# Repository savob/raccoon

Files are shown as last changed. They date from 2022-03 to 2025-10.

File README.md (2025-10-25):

# Raccoon

A little raccoon trinket based on an ATtiny and capacitive sensing. The premise is simple, a small circuitboard decorated to be a raccoon on one side has circuitry mounted on the back to illuminate the LED eyes when a touch is detected on the raccoon. Designed to maximize battery life and run of standard coin cells.

My first foray into making PCB art hardwarewise, and both capacitive sensing and really trying to supress power draw with coding.

_All this artwork was drawn by my lovely sister, Dorotea Bajic. Check out their website [dorotea.ca](https://dorotea.ca/), it's far nicer looking than my own._

# Code

The code is pretty simple for the first two revisions given the scope of the projects, and a minor hack was used to get revision 1.0 working. I used the Arduino framework for the first revision but have since moved to using Microchip's own MPLAB to make full use of the chips.

# Hardware

The electrical design of the system is simple, a microcontroller powered directly from a coin cell battery that is connected to a couple LEDs, a capacitance detection pad, and a select few passive components. The challenge with the board for this was the artwork and making it look nice.

Initially an ATtiny85 was selected but later I switched to the tinyAVR 1-series due to dedicated capacitive sensing hardware and reduced power consumption.

# Software Used

KiCad is used to design the hardware, version 9 as of writing.

Arduino IDE 1.8.13 was used to program revision 1.0. MPLAB for revisions 2.0 onwards.

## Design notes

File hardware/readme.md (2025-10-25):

# Raccoon Hardware Files

The folders `raccoon_revX` are the actual KiCad projects, `raccoon-art` is the collection of footprints for the artwork derived from the images in the [media](../media/) folder.

# Revision 1.0

These design files are the lightly adjusted version of the original raccoon hardware, to address the hardware bugs related to the programming interface.

# Revision 2.0

A continuation of the work done for the files shared as "Revision 1". Changes from the previous revision:

- Complete removal of the ATtiny85 in favour of the ATtiny1617 _which is definitely overkill for this task but what I had on hand._
- Moved to using a TagConnect programming header to simplify programming. _This does slightly affect the art on the front._
- Added a jumper to cut for current measurement

# Revision 3.0

Tweaking the design of revision 2.0. Changes from the previous revision:

- Changed the main microcontroller to a 1616 since we don't need many GPIO, but I want flash space to try different eye effects, maybe even changing with each touch
- Removed unnecessary passives; the sense resistor, VREF capacitor, secondary decoupling capacitor (100n)
- Split the LED lines for individual eye control, via PWM
- Moved the programming pads to be closer to the edge so some alignment pins align to the PCB outline instead of needing holes in the PCB
- Moved the LED current limiting resistors to be closer to the microcontroller and out of the path of the coin cell
- Added a keepout zone for pour near the current measurement jumper to avoid cutting and then shorting VCC to GND

# Software Used

KiCad version 9 was used for all project files.

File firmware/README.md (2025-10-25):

# Firmware

With each change of hardware, the firmware needed to change too. This contains the firmware for all revisions.

## Software Used

Arduino IDE 1.8.13 was used to program the microcontroller for the first deign, but in later revisions I moved to MPLAB to try it out and was pleased with the results.

# Revision 1.0 - `sleepingCapSense`

I used the [TinyTouchLib](https://github.com/cpldcpu/TinyTouchLib) library made by [cpldcpu](https://github.com/cpldcpu). I had some issues using it as a conventional library in Arduino, so I opted to simply copy the files I needed directly into the sketch folder and modified them slightly to work. Other than the file modifications required to get it to compile, I only changed the the sensitivities to suit the final circuit board and pad. Otherwise the code I use related to capacitive sensing in my sketch is taken directly from the library's example.

The code simply checks for if there is a press event and then flashes the eyes.

## Power Reduction

This relies heavily on the `avr/power` library, and some of my own register manipulations to disable features and put the microcontroller into sleep for the majority of the timer. The watchdog timer (WDT) is used to awake the system periodically to perform the sensing routine. 

## ATtiny85 Support

Support for this microcontroller in the Arduino IDE is provided by the [ATTinyCore](https://github.com/SpenceKonde/ATTinyCore) project hosted by [Spence Konde](https://github.com/SpenceKonde).

# Revision 2.0 - `raccoon_rev_2_0.X`

I didn't intend to change the behaviour of the system, I just wanted to port what working in Rev. 1.0 to the ATtiny1617 from the ATtiny85.

Since I was moving to the to the tinyAVR 1-series of chips with the ATtiny1617, I would need to rewrite the entire firmware for the new hardware, especially to make use of the 1617's built in Peripheral Touch Controller (PTC) peripheral for capacitive sensing rather than the ADC trickery used in revision 1.0. 

Since I was basically starting from scratch, I took the opprotunity to try out Microchip's own toolchain and pivoted to using MPLAB. Once I learned my way though their project configuration system **I had the firmware complete in a single evening!**

## Power Reduction

Using the generated project files from MPLAB and following their example after specifying "low-power" for my capacitive sensing pad the performance was what I hoped for! I measured an average current draw of 15&nbsp;uA when sensing which was better than revision 1.0, and it was also more responsive! Kudos to their team! 

# Revision 3.0 - `raccoon_rev_3_0.X`

I've prepared the core of the project in MPLAB, but I haven't actually written code yet to drive the LEDs with PWM (I previously just used conventional digital outputs).

With revision 3.0 I would like to take the time to try out more effects to make it seem a bit more lifelike and amusing to interact with compared to earlier revisions. Some ideas:

- Diming them instead of hard on/offs
- Having the LED brightness not be synchronized between eyes, as though its "eye"s are opening cartoonishly out of slumber
- Using an intermediate level of brightness and then repeated touches make it go full power

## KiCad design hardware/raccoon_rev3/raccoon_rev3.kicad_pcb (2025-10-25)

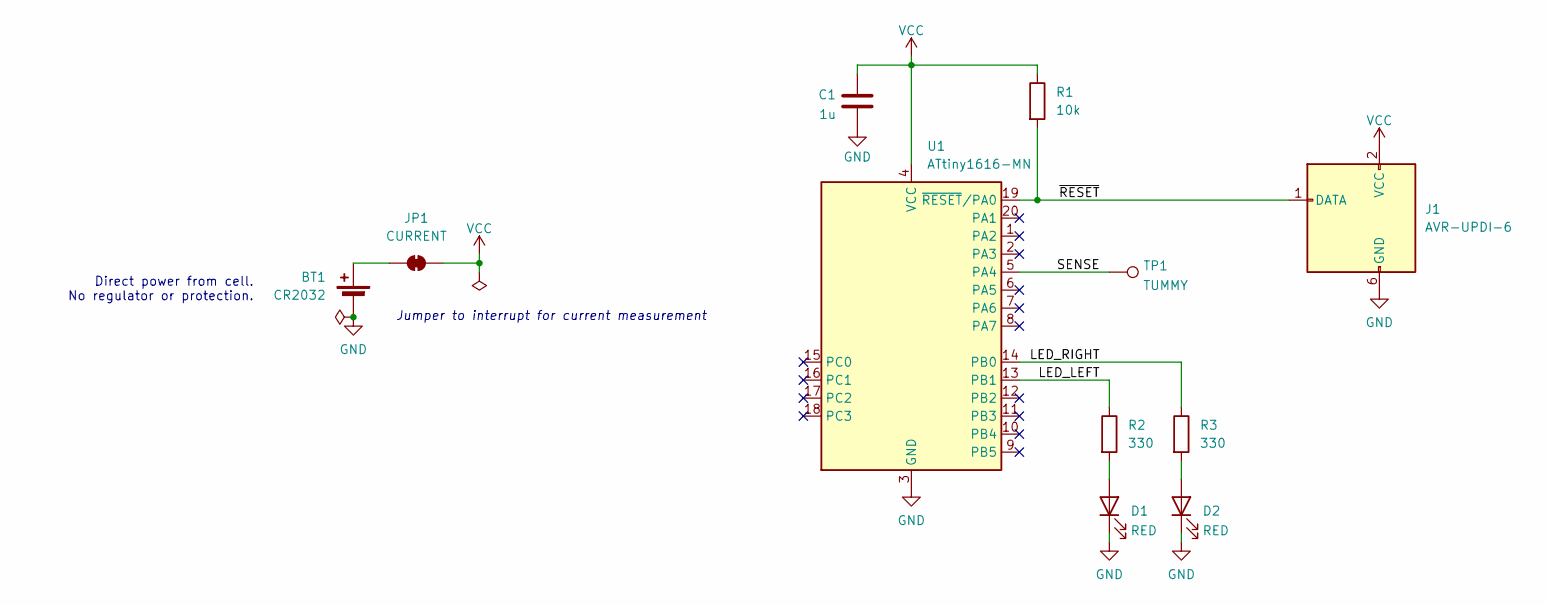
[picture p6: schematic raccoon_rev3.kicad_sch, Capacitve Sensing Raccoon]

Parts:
BT1: CR2032; BatteryHolder_Multicomp_BC-2001_1x2032; Manufacturer PN MY-2032-05; LCSC C964830
C1: 1u; C_0603_1608Metric; Manufacturer PN CL10A105KB8NNNC; LCSC C15849
D1, D2: RED; D_0805_2012Metric; Manufacturer PN LTST-C170KRKT; LCSC C94868
J1: AVR-UPDI-6; Tag-Connect_TC2030-IDC-NL_2x03_P1.27mm_Vertical
JP1: CURRENT; SolderJumper-2_P1.3mm_Bridged2Bar_Pad1.0x1.5mm
R1: 10k; R_0603_1608Metric; Manufacturer PN 0603WAF1002T5E; LCSC C25804
R2, R3: 330; R_0603_1608Metric; Manufacturer PN 0603WAF3300T5E; LCSC C23138
TP1: TUMMY; tummy
U1: ATtiny1616-MN; VQFN-20-1EP_3x3mm_P0.4mm_EP1.7x1.7mm; Manufacturer PN ATTINY1616-MNR; LCSC C507118

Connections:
/LED_LEFT: R2.1, U1.13 (PB1)
/LED_RIGHT: R3.1, U1.14 (PB0)
/SENSE: TP1.1, U1.5 (PA4)
/~RESET: J1.1 (DATA), R1.2, U1.19 (~RESET/PA0)
GND: BT1.2 (-), C1.2, D1.1 (K), D2.1 (K), J1.6 (GND), U1.3 (GND), U1.21 (GND)
unnamed: BT1.1 (+), JP1.1 (A)
unnamed: D1.2 (A), R2.2
unnamed: D2.2 (A), R3.2
VCC: C1.1, J1.2 (VCC), JP1.2 (B), R1.1, U1.4 (VCC)

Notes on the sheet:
Jumper to interrupt for current measurement
Direct power from cell. No regulator or protection.

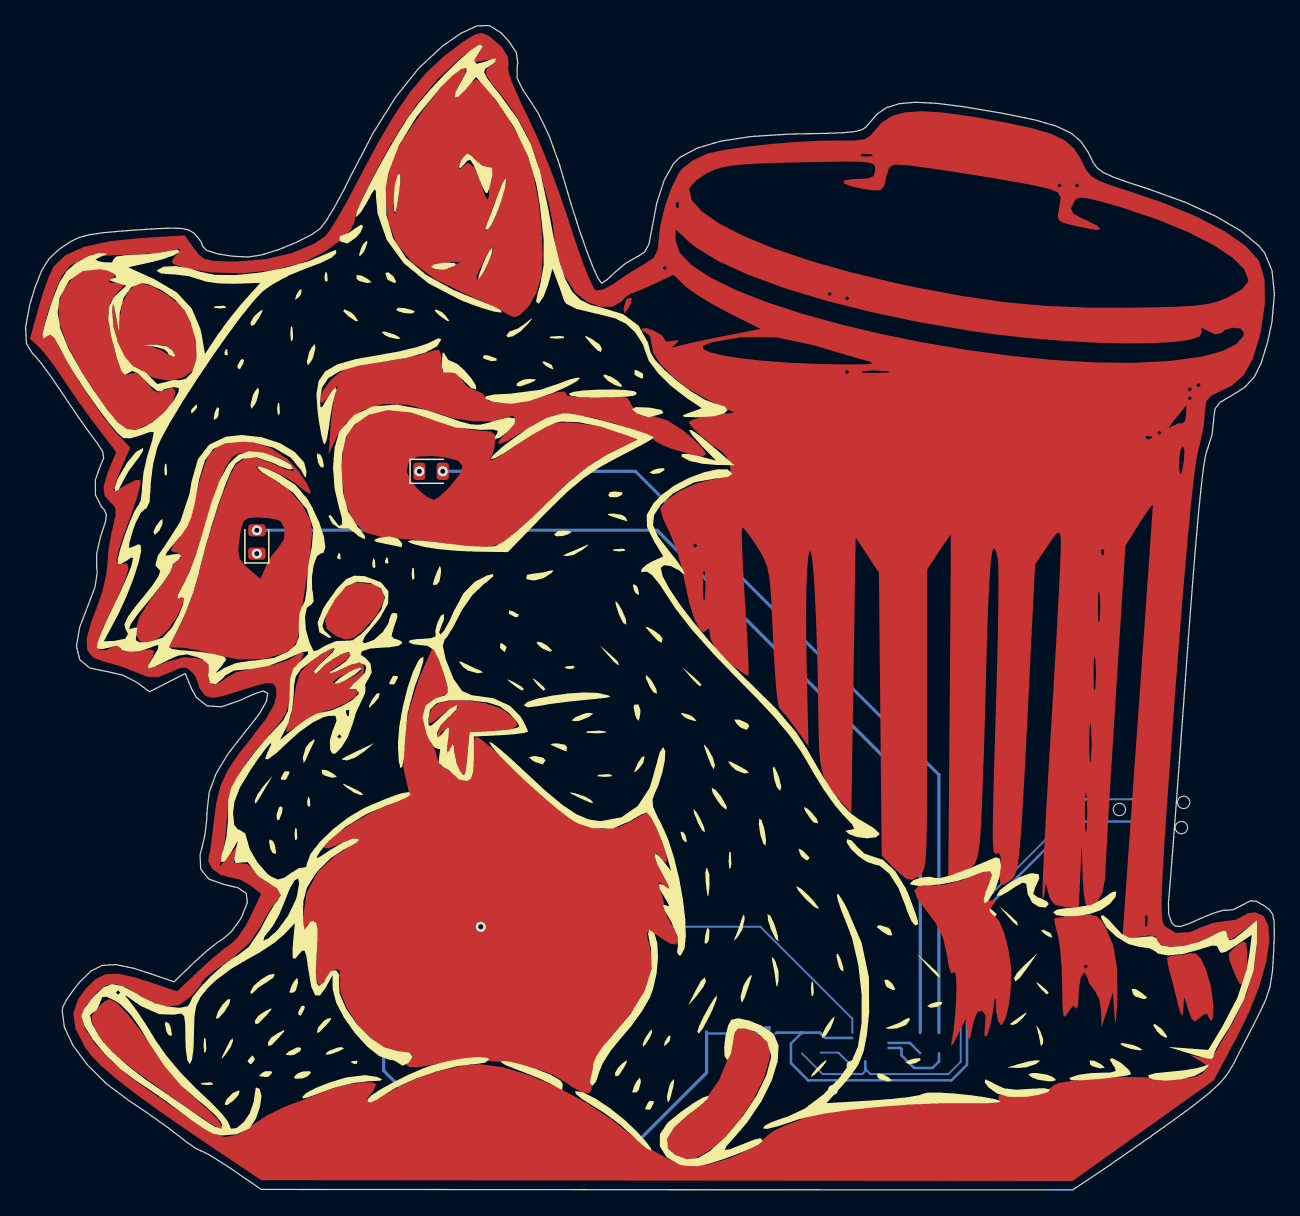
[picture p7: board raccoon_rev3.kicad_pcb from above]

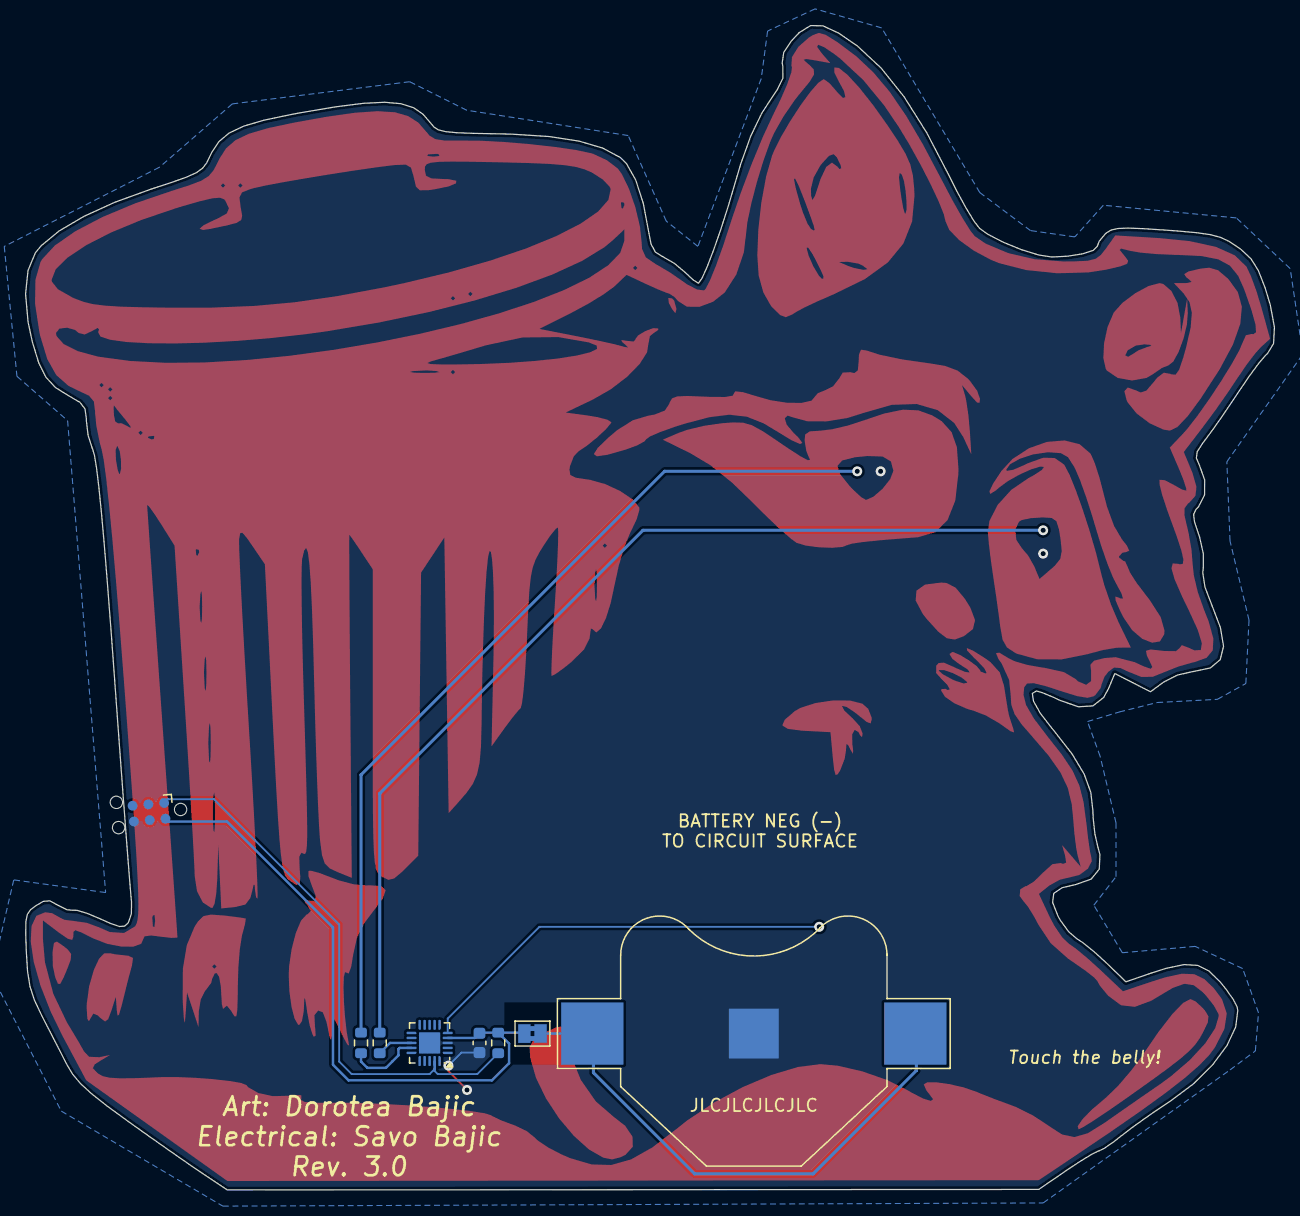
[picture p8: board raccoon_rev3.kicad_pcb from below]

Board: 2 copper layers, 100.2 x 93.4 mm, 11 parts (8 on the bottom side), 9 nets.

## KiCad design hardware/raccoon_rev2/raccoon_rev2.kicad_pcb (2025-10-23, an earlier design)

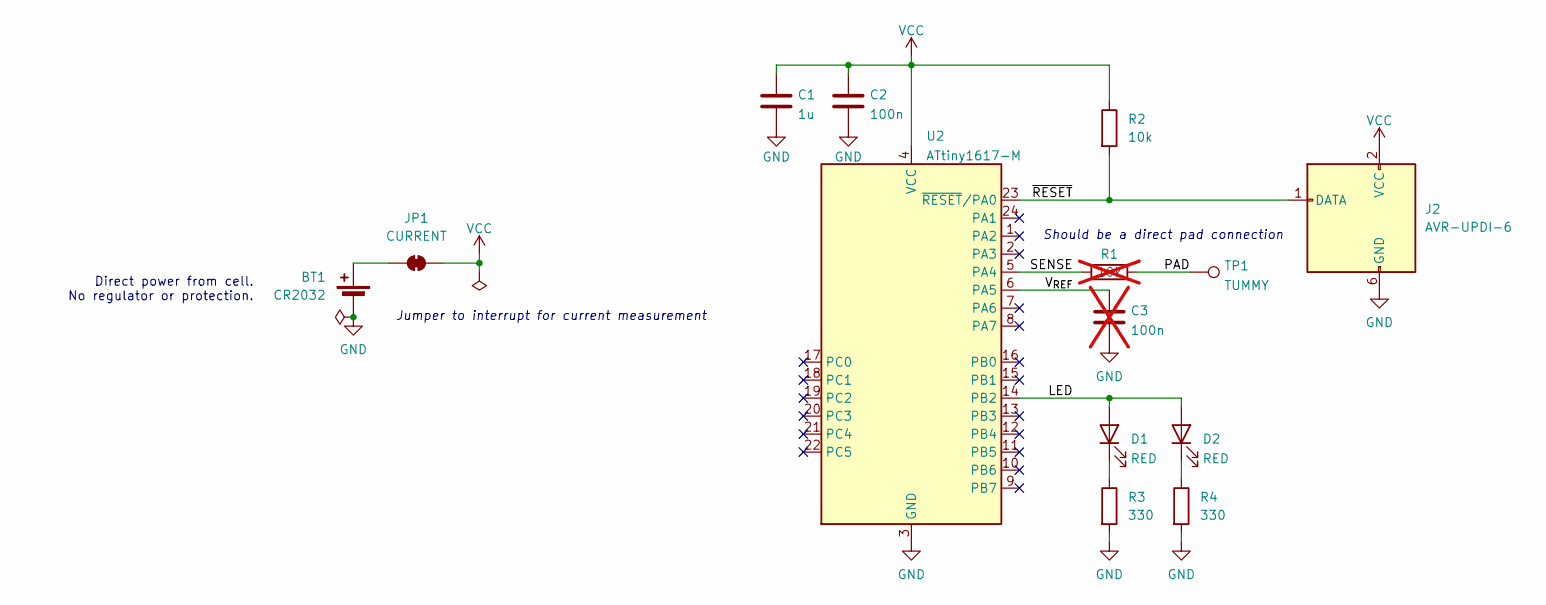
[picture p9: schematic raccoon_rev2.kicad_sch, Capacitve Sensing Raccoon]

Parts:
BT1: CR2032; BatteryHolder_Multicomp_BC-2001_1x2032; Manufacturer PN MY-2032-05; LCSC C964830
C1: 1u; C_0603_1608Metric; Manufacturer PN CL10A105KB8NNNC; LCSC C15849
C2: 100n; C_0603_1608Metric; Manufacturer PN CC0603KRX7R9BB104; LCSC C14663
C3: 100n; C_0603_1608Metric; Manufacturer PN CC0603KRX7R9BB104; LCSC C14663; not fitted
D1, D2: RED; D_0805_2012Metric; Manufacturer PN LTST-C170KRKT; LCSC C94868
J2: AVR-UPDI-6; Tag-Connect_TC2030-IDC-NL_2x03_P1.27mm_Vertical
JP1: CURRENT; SolderJumper-2_P1.3mm_Bridged2Bar_Pad1.0x1.5mm
R1: 10k; R_0603_1608Metric; Manufacturer PN 0603WAF1002T5E; LCSC C25804; not fitted
R2: 10k; R_0603_1608Metric; Manufacturer PN 0603WAF1002T5E; LCSC C25804
R3, R4: 330; R_0603_1608Metric; Manufacturer PN 0603WAF3300T5E; LCSC C23138
TP1: TUMMY; tummy
U2: ATtiny1617-M; QFN-24-1EP_4x4mm_P0.5mm_EP2.6x2.6mm; Manufacturer PN ATTINY1617-MNR; LCSC C614176

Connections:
/LED: D1.2 (A), D2.2 (A), U2.14 (PB2)
/PAD: R1.2, TP1.1
/SENSE: R1.1, U2.5 (PA4)
/V_{REF}: C3.1, U2.6 (PA5)
/~RESET: J2.1 (DATA), R2.2, U2.23 (~RESET/PA0)
GND: BT1.2 (-), C1.2, C2.2, C3.2, J2.6 (GND), R3.2, R4.2, U2.3 (GND), U2.25 (GND)
unnamed: BT1.1 (+), JP1.1 (A)
unnamed: D1.1 (K), R3.1
unnamed: D2.1 (K), R4.1
VCC: C1.1, C2.1, J2.2 (VCC), JP1.2 (B), R2.1, U2.4 (VCC)

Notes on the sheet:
Should be a direct pad connection
Jumper to interrupt for current measurement
Direct power from cell. No regulator or protection.

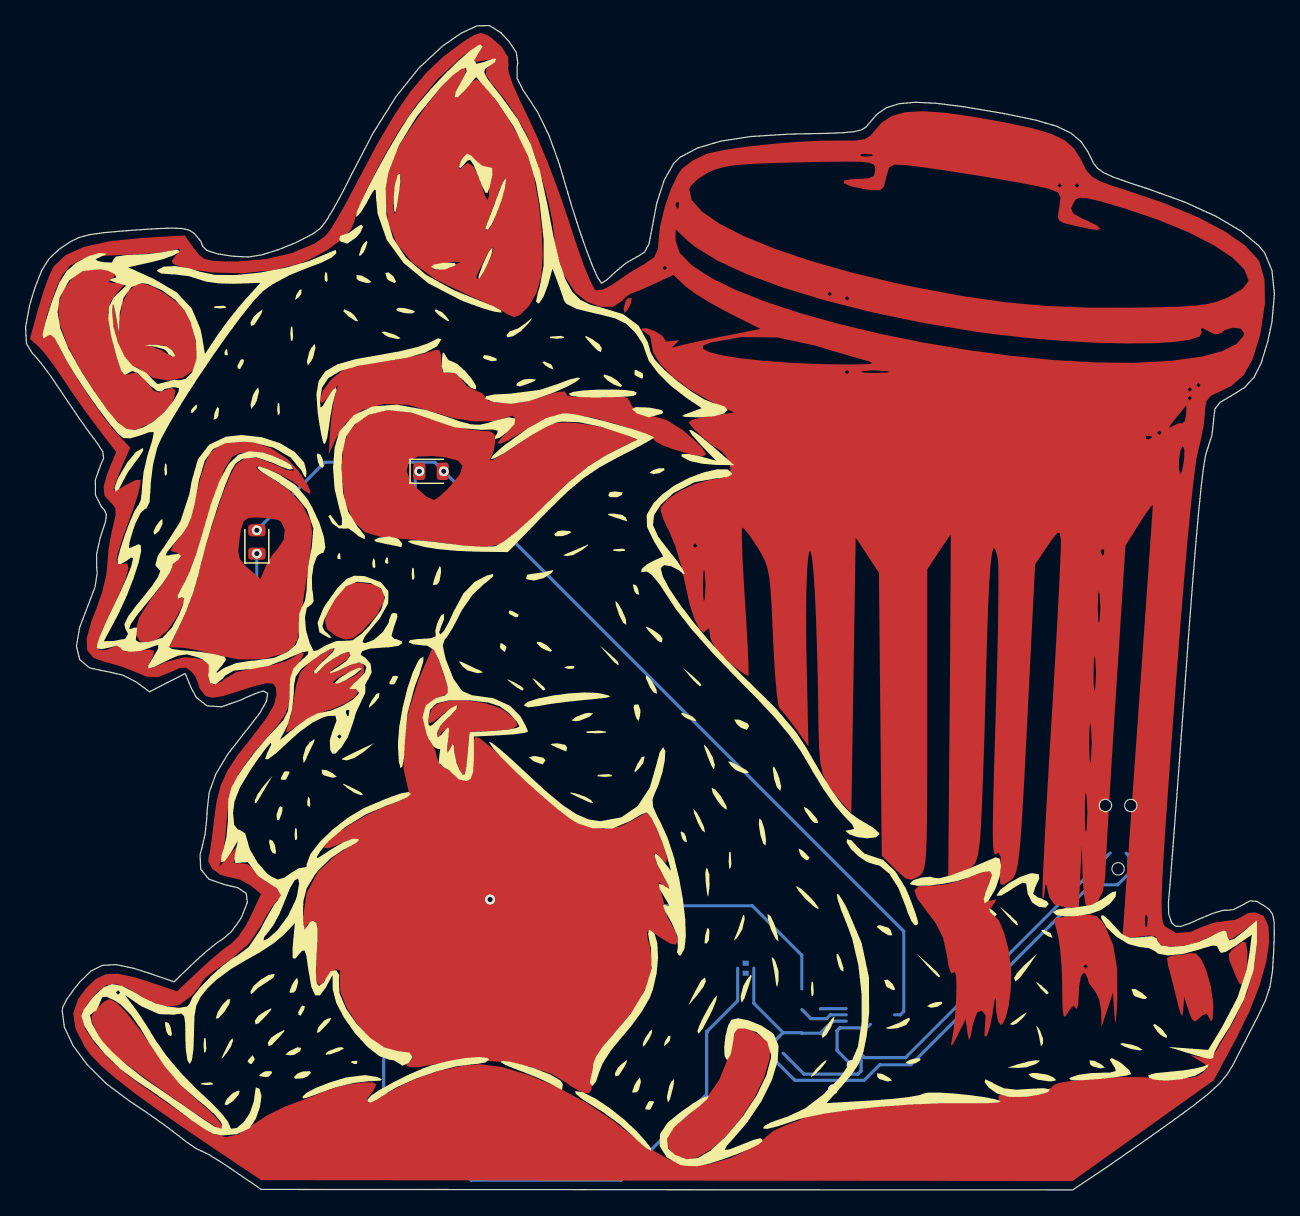
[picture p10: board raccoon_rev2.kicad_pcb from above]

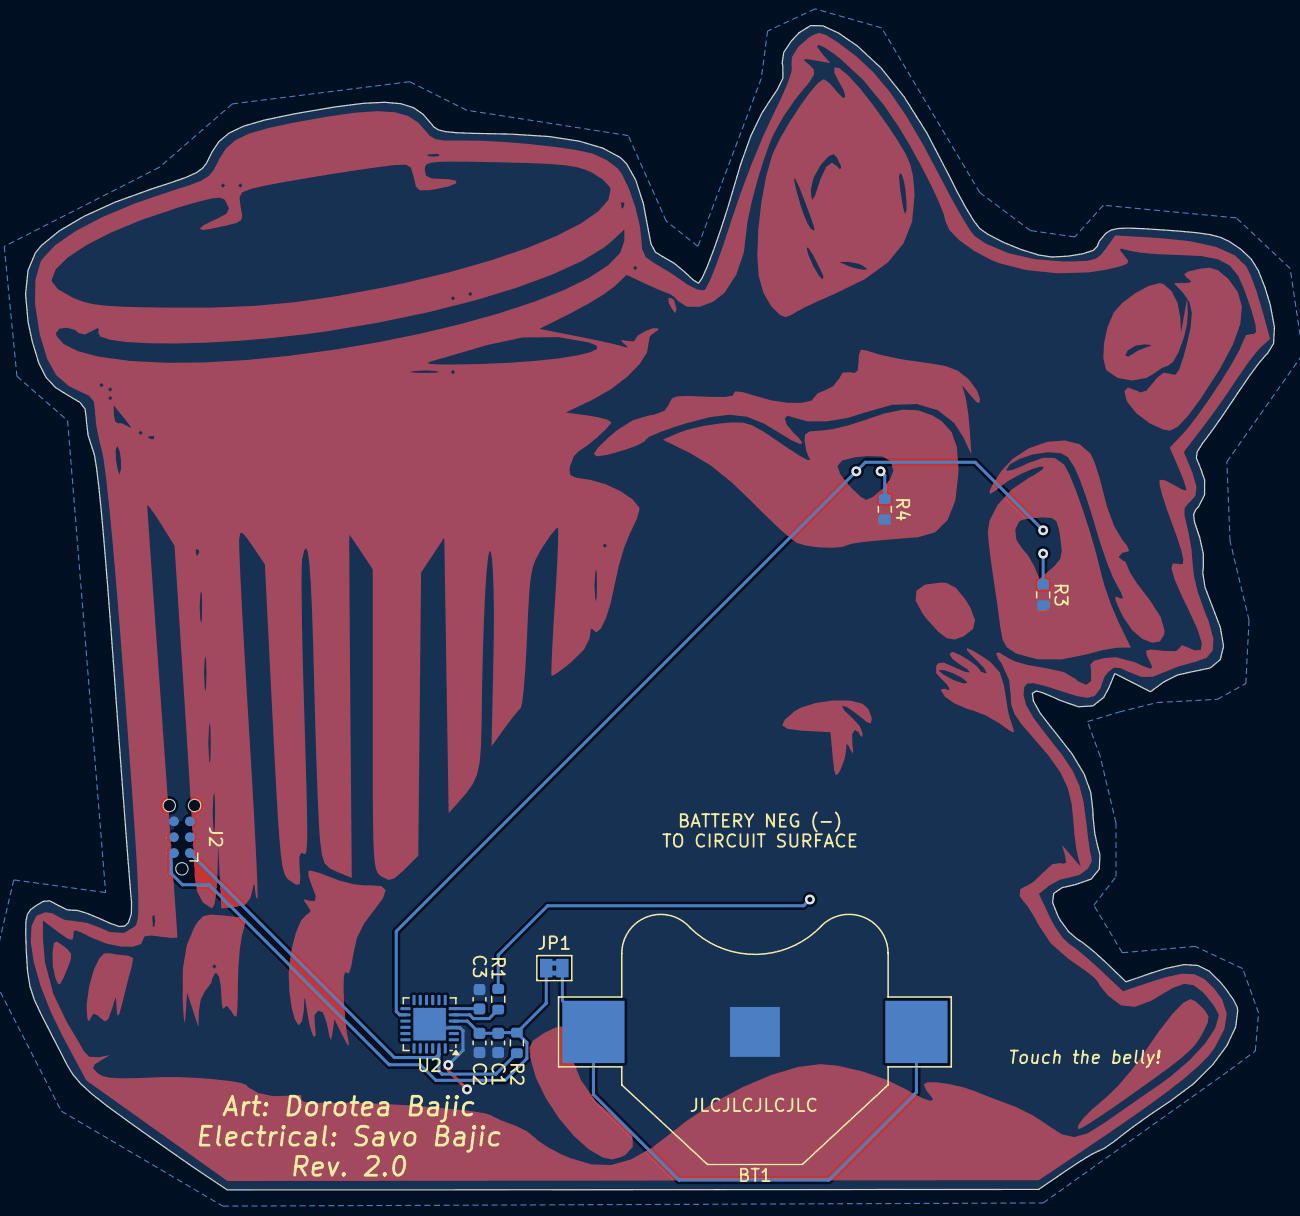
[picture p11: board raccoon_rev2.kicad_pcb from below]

Board: 2 copper layers, 100.2 x 93.4 mm, 14 parts (11 on the bottom side), 10 nets.

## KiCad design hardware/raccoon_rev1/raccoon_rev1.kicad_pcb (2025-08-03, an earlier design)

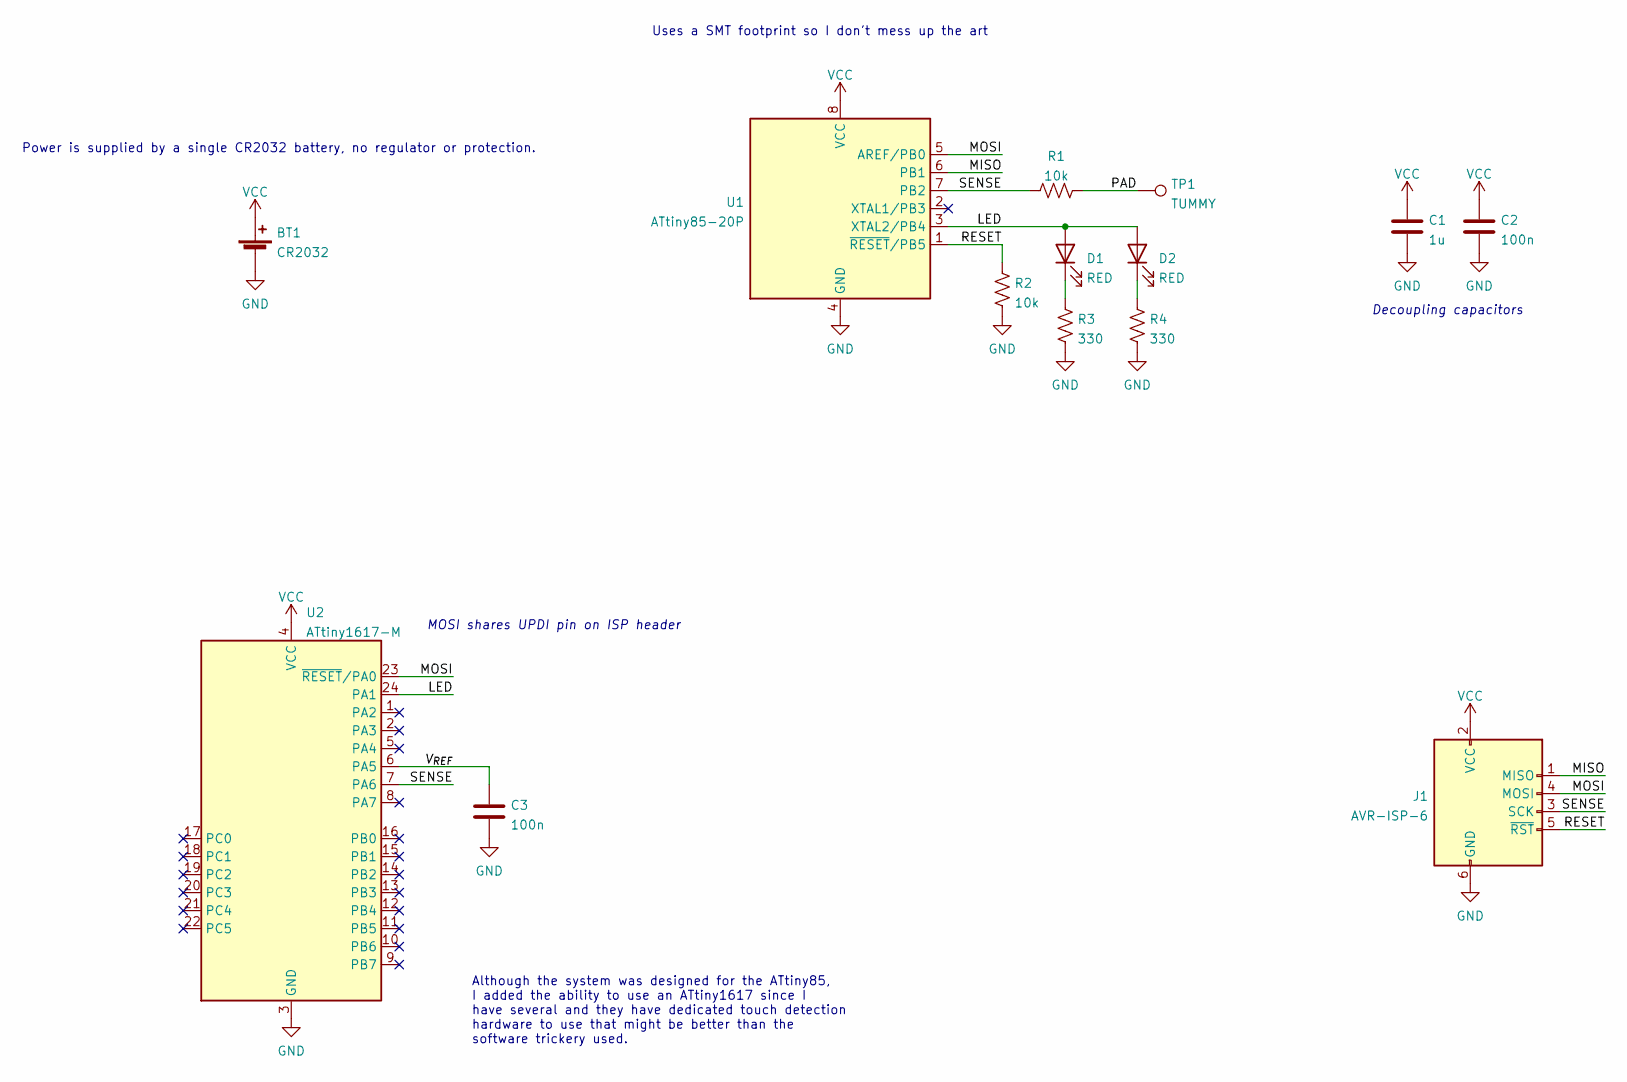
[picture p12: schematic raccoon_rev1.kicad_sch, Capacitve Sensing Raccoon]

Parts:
BT1: CR2032; BatteryHolder_Keystone_3002_1x2032
C1: 1u; C_0603_1608Metric
C2, C3: 100n; C_0603_1608Metric
D1, D2: RED; D_0805_2012Metric
J1: AVR-ISP-6; PinHeader_2x03_P2.54mm_Vertical_SMD
R1, R2: 10k; R_0603_1608Metric
R3, R4: 330; R_0603_1608Metric
TP1: TUMMY; tummy
U1: ATtiny85-20P; DIP-8_W7.62mm_SMDSocket_SmallPads
U2: ATtiny1617-M; QFN-24-1EP_4x4mm_P0.5mm_EP2.6x2.6mm

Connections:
/LED: D1.2 (A), D2.2 (A), U1.3 (XTAL2/PB4), U2.24 (PA1)
/MISO: J1.1 (MISO), U1.6 (PB1)
/MOSI: J1.4 (MOSI), U1.5 (AREF/PB0), U2.23 (~RESET/PA0)
/PAD: R1.2, TP1.1
/RESET: J1.5 (~RST), R2.1, U1.1 (~RESET/PB5)
/SENSE: J1.3 (SCK), R1.1, U1.7 (PB2), U2.7 (PA6)
/V_{REF}: C3.1, U2.6 (PA5)
GND: BT1.2 (-), C1.2, C2.2, C3.2, J1.6 (GND), R2.2, R3.2, R4.2, U1.4 (GND), U2.3 (GND), U2.25 (GND)
unnamed: D1.1 (K), R3.1
unnamed: D2.1 (K), R4.1
VCC: BT1.1 (+), C1.1, C2.1, J1.2 (VCC), U1.8 (VCC), U2.4 (VCC)

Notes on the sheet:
Although the system was designed for the ATtiny85, I added the ability to use an ATtiny1617 since I have several and they have dedicated touch detection hardware to use that might be better than the software trickery used.
MOSI shares UPDI pin on ISP header
Decoupling capacitors
Power is supplied by a single CR2032 battery, no regulator or protection.
Uses a SMT footprint so I don't mess up the art

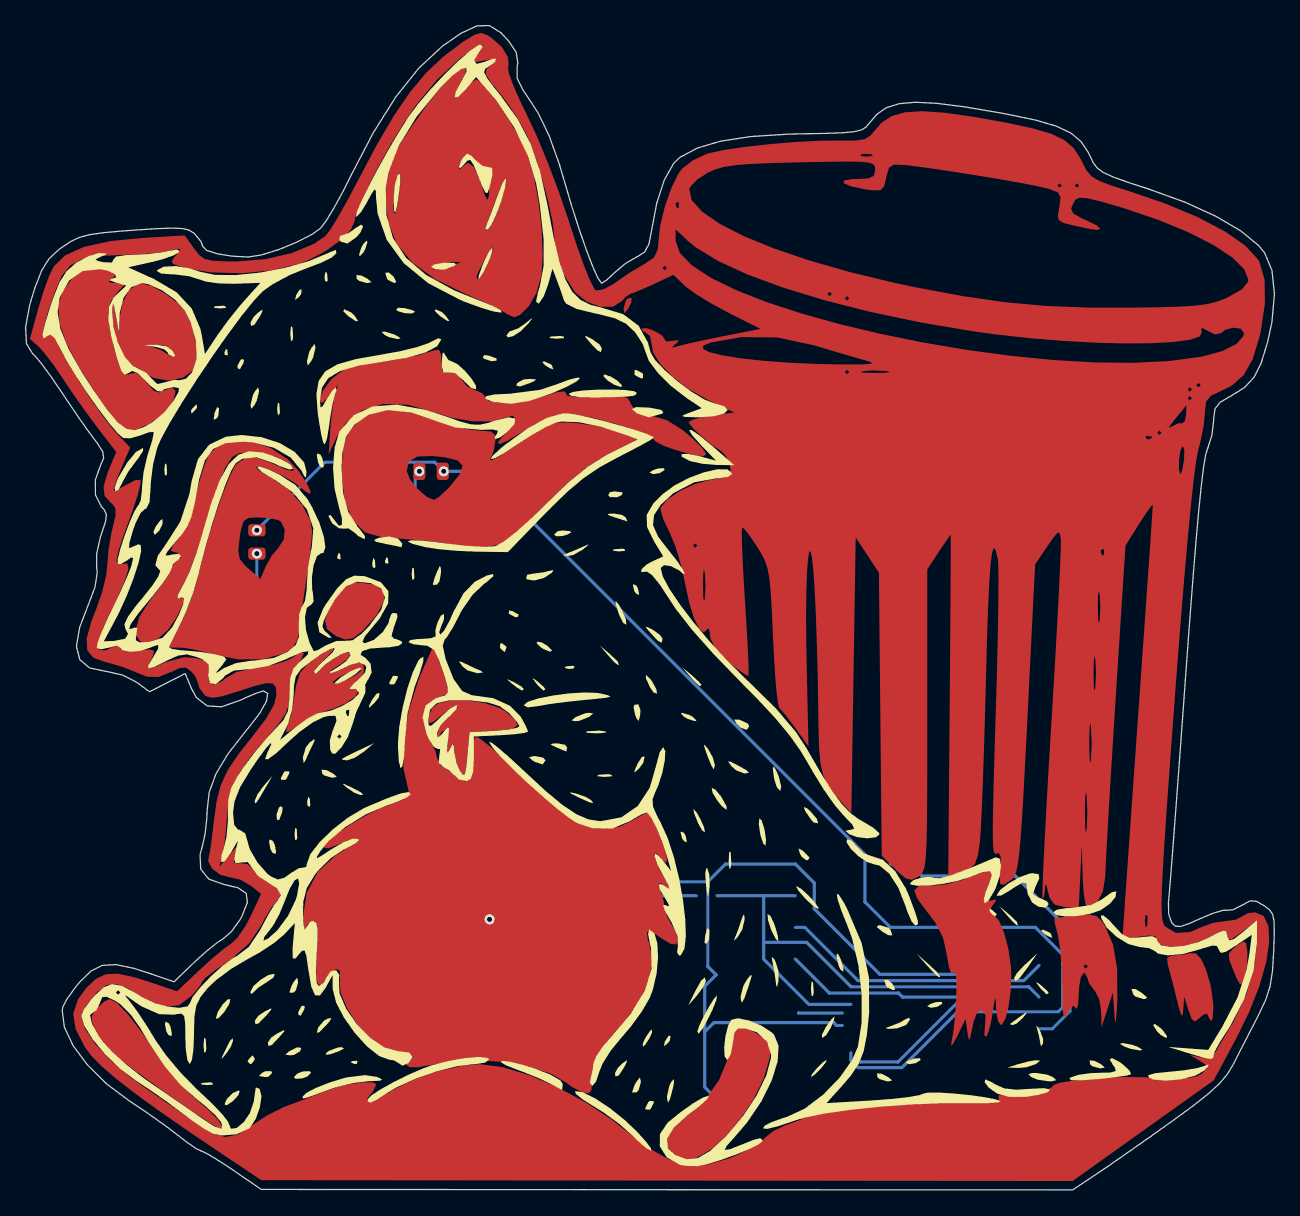
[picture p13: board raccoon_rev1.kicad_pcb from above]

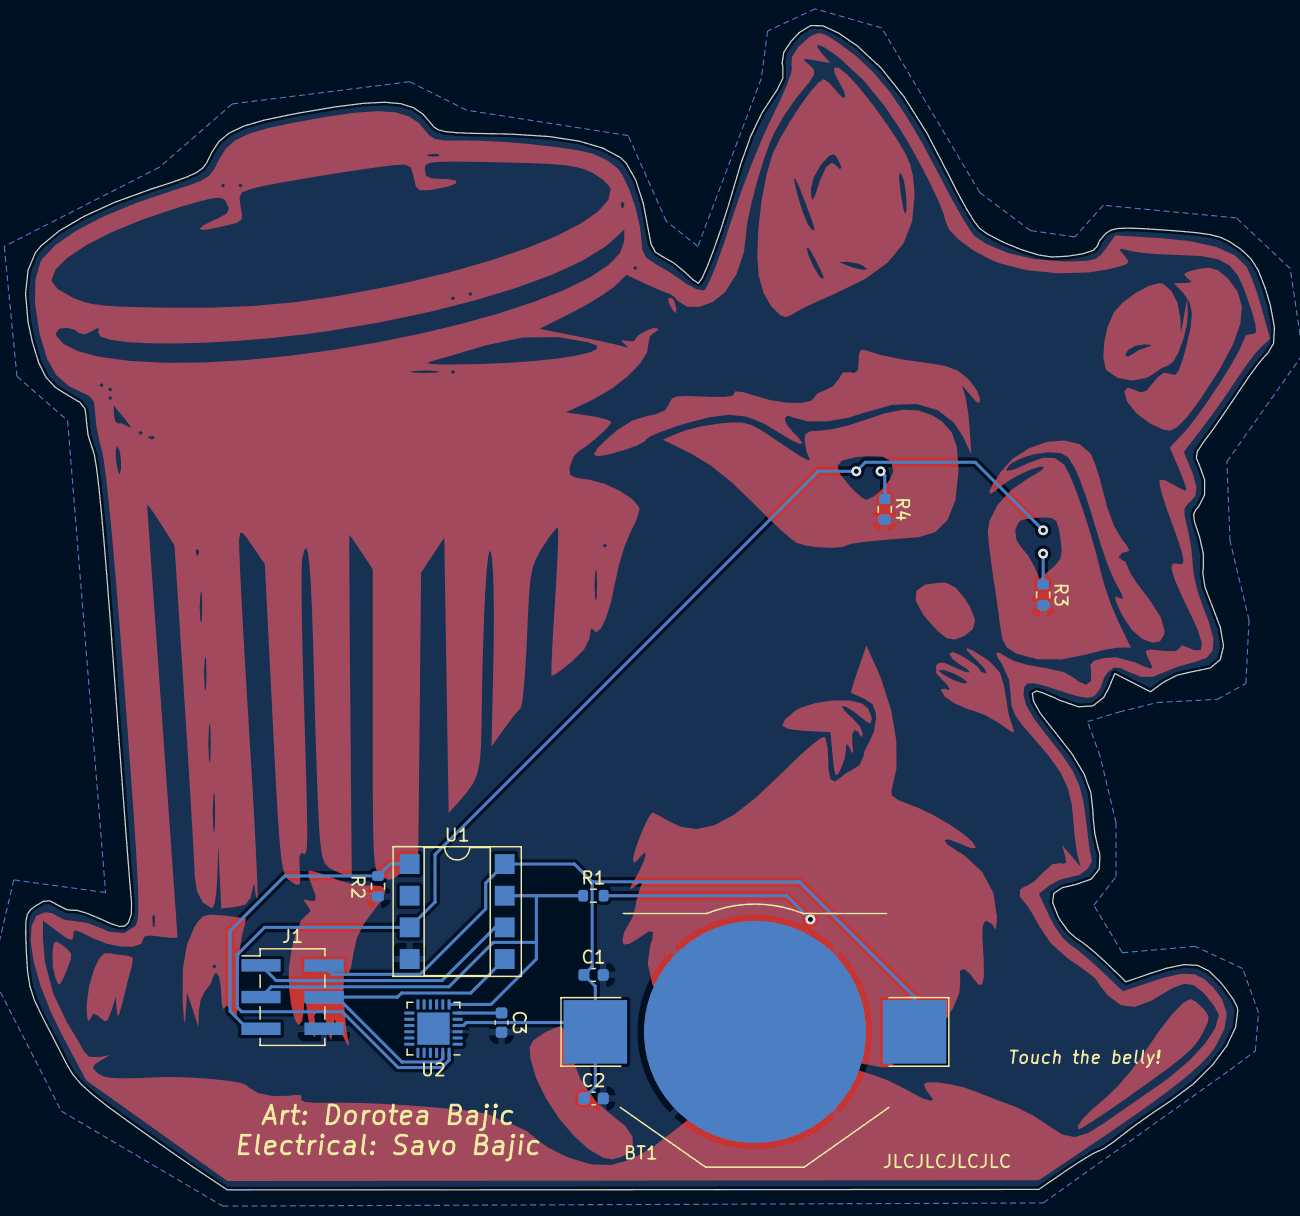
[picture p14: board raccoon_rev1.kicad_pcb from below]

Board: 2 copper layers, 100.2 x 93.4 mm, 14 parts (11 on the bottom side), 11 nets.

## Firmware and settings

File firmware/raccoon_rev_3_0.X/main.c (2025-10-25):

 /*
 * MAIN Generated Driver File
 * 
 * @file main.c
 * 
 * @defgroup main MAIN
 * 
 * @brief This is the generated driver implementation file for the MAIN driver.
 *
 * @version MAIN Driver Version 1.0.2
 *
 * @version Package Version: 3.1.2
*/

/*
© [2025] Microchip Technology Inc. and its subsidiaries.

    Subject to your compliance with these terms, you may use Microchip 
    software and any derivatives exclusively with Microchip products. 
    You are responsible for complying with 3rd party license terms  
    applicable to your use of 3rd party software (including open source  
    software) that may accompany Microchip software. SOFTWARE IS ?AS IS.? 
    NO WARRANTIES, WHETHER EXPRESS, IMPLIED OR STATUTORY, APPLY TO THIS 
    SOFTWARE, INCLUDING ANY IMPLIED WARRANTIES OF NON-INFRINGEMENT,  
    MERCHANTABILITY, OR FITNESS FOR A PARTICULAR PURPOSE. IN NO EVENT 
    WILL MICROCHIP BE LIABLE FOR ANY INDIRECT, SPECIAL, PUNITIVE, 
    INCIDENTAL OR CONSEQUENTIAL LOSS, DAMAGE, COST OR EXPENSE OF ANY 
    KIND WHATSOEVER RELATED TO THE SOFTWARE, HOWEVER CAUSED, EVEN IF 
    MICROCHIP HAS BEEN ADVISED OF THE POSSIBILITY OR THE DAMAGES ARE 
    FORESEEABLE. TO THE FULLEST EXTENT ALLOWED BY LAW, MICROCHIP?S 
    TOTAL LIABILITY ON ALL CLAIMS RELATED TO THE SOFTWARE WILL NOT 
    EXCEED AMOUNT OF FEES, IF ANY, YOU PAID DIRECTLY TO MICROCHIP FOR 
    THIS SOFTWARE.
*/
#include "mcc_generated_files/system/system.h"
#include "mcc_generated_files/timer/delay.h"
#include "mcc_generated_files/touch/touch.h"

// Needed to get some variables from touch system
extern volatile uint8_t measurement_done_touch;
extern volatile uint8_t time_to_measure_touch_flag;

const uint16_t FLASH_PERIOD_MS = 3000;
const uint8_t START_FLASHES = 5;


int main(void)
{
    SYSTEM_Initialize();
    
    for (uint8_t i = 0; i < START_FLASHES; i++) {
//        LED_SetHigh();
        DELAY_milliseconds(FLASH_PERIOD_MS / 5);
//        LED_SetLow();
        DELAY_milliseconds(FLASH_PERIOD_MS / 5); 
    }
    
    while(1) {
        touch_process();
#if (DEF_TOUCH_LOWPOWER_ENABLE == 1u)
        if (time_to_measure_touch_flag != 1u) {
             __asm__ __volatile__ ( "sleep" "\n\t" :: );
        }
#endif
        
        if(measurement_done_touch == 1) {
            measurement_done_touch = 0;
            
            uint8_t key_status = get_sensor_state(0) & KEY_TOUCHED_MASK;
            if (0u == key_status) continue;
            
//            LED_SetHigh();
            DELAY_milliseconds(FLASH_PERIOD_MS);
//            LED_SetLow();
            // DELAY_milliseconds(FLASH_PERIOD_MS / 10); // Stay off for a bit?
        }
    }    
}

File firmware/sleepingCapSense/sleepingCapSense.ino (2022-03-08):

// Written for use on the ATtiny85

#include <avr/sleep.h>
#include <avr/interrupt.h>
#include <avr/power.h>
#include "tinyTouch.h"

const int eyesOnTime = 3000; // Time eyes are on in ms after touched
const byte eyesPin = 4;

void setup() {

  for (int x = 0; x < 5; x++) {
    pinMode(x, OUTPUT); digitalWrite(x, LOW);
  }

//  CLKPR = _BV(CLKPCE);
//  CLKPR = 0;    // set clock prescaler to 1 (attiny 25/45/85/24/44/84/13/13A)

  tinytouch_init();


  // Set sleep mode
  set_sleep_mode(SLEEP_MODE_PWR_DOWN);

  setup_watchdog();

  // Light on to confirm power on
  digitalWrite(eyesPin, HIGH);
  delay(eyesOnTime);
  digitalWrite(eyesPin, LOW);

    // Trying to reduce power use
  ACSR |= _BV(ACD); // Disable analog comparator
  DIDR0 = _BV(AIN1D) | _BV(AIN0D); // Disable digital input buffers on analog pins (we don't need digital in)
  PRR = _BV(PRTIM1) | _BV(PRTIM0) | _BV(PRUSI) | _BV(PRADC);
}

void loop() {

  // Sleep cycle
  ADCSRA &= ~(_BV(ADEN)); // Disable ADC
  __power_all_disable();
  sleep_mode();
  sleep_disable();
  __power_all_enable();
  ADCSRA |= _BV(ADEN); // Enable ADC
  delay(10); // Needed for ADC warmup/stabilization

  // Check for touch and light up
  if (tinytouch_sense() == tt_push) {
    digitalWrite(eyesPin, HIGH);
    delay(eyesOnTime);
    digitalWrite(eyesPin, LOW);
  }
}

void setup_watchdog() {
  MCUSR &= ~_BV(WDRF); // Reset WDT

  // Start timed sequence to set
  WDTCR |= _BV(WDCE) | _BV(WDE);
  
  // Set new watchdog timeout value 
//  WDTCR = _BV(WDCE) | _BV(WDP3) | _BV(WDP0); // 8 seconds
  WDTCR = _BV(WDCE) | _BV(WDP2) | _BV(WDP1) | _BV(WDP0); // 2 seconds
//  WDTCR = _BV(WDCE) | _BV(WDP2) | _BV(WDP1); // 1 second
//  WDTCR = _BV(WDCE) | _BV(WDP2) | _BV(WDP0); // 0.5 seconds
  
  WDTCR |= _BV(WDIE);
}

ISR (WDT_vect) {
  // Do nothing, just escape sleep
}

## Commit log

2022-03-07 Updated code to boards
    Reflected some changes needed on the boards, namely pin allocations for capacitance sensing and increased the frequency of touch checks. Some formatting was updated too.
2022-03-21 Uploaded hardware files
    The hardware files uploaded are the revised version. They fix the programming header issue I had (but not the "sense" connection). I included a zip with the "original" version I had manufactured.
    [raccoon.kicad_pcb, raccoon.kicad_sch]
2024-01-04 Updating project to KiCad 7
    [raccoon.kicad_pcb, raccoon.kicad_sch]
2025-08-03 Hardware revision 2.0
    [raccoon.kicad_pcb, raccoon.kicad_sch, raccoon_rev1.kicad_pcb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]
2025-09-02 Added alternate PN as ordered
    [raccoon_rev2.kicad_pcb, raccoon_rev2.kicad_sch]
2025-10-21 Minor hardware assembly changes
2025-10-22 Touching up compiler options
    [Config_1.txt, Config_2.txt]
2025-10-23 Updated components being placed
    [raccoon_rev2.kicad_pcb, raccoon_rev2.kicad_sch]
2025-10-25 Added designs and preliminary hardware for revision 3.0
    [raccoon_rev3.kicad_pcb, raccoon_rev3.kicad_sch]
